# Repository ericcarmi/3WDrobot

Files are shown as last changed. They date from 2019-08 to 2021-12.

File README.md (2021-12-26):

# 3WD omnidirectional robot

This repo has code for Arduino (control) and ROS (network, GUI).
Also contains CAD files: camera mount, stepper motor/linear actuator to move a microphone up and down. 

The motiviation for this EEE Master's project was from a physics Senior project (an undergrad course) where I designed, 3D printed, and measured an acoustic lens in the anechoic chamber at CSUS. Measuring was tedious and not very precise, so making a robot to do the measuring seemed like a good next step. I only had one semester to do the EEE Master's project, so the solution is not "pretty". I brought the chassis for the robot but I did everything else myself: programming the controls (kinematics for 3-wheel drive), designing and 3D printer attachments (camera holders, linear actuator for mic movement), and programming the UI to control and monitor the robot (in ROS).  

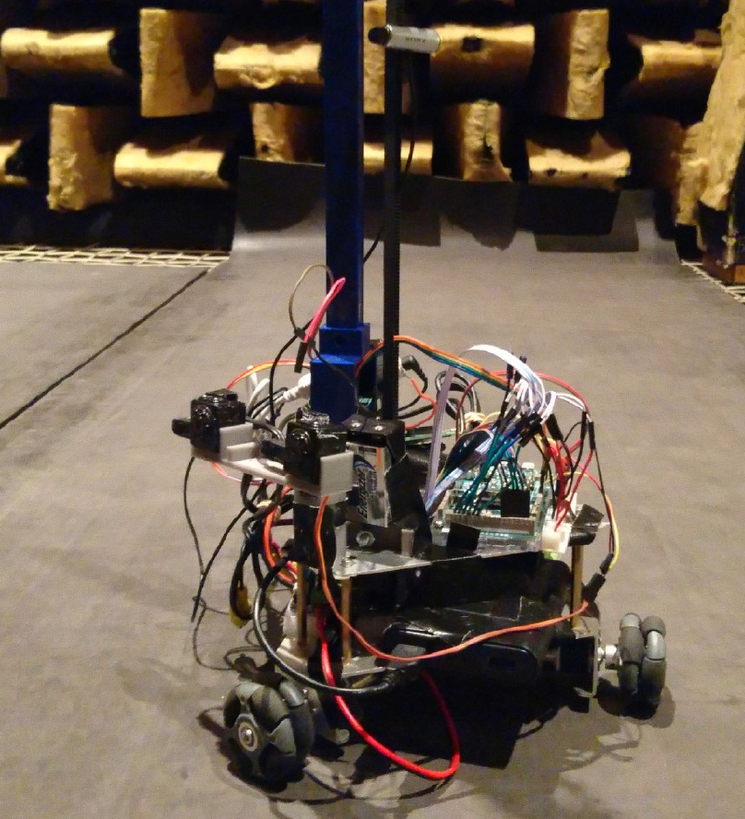
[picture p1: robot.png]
Robot in the anechoic chamber 3WD robot


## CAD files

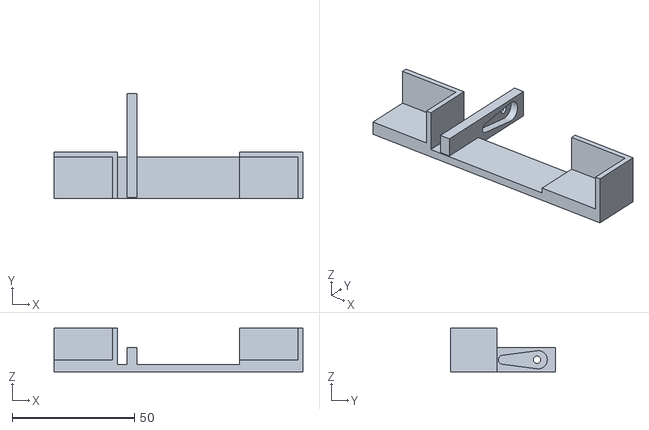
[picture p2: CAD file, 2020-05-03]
CAD files/cammountMain.stl
102.0 x 43.0 x 18.0

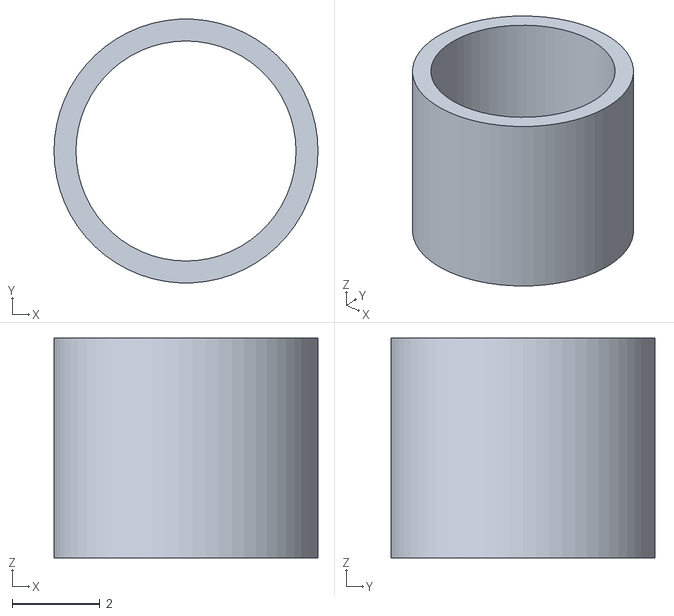
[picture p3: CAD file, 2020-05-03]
CAD files/lens/spacer.stl
6.00 x 5.99 x 5.00

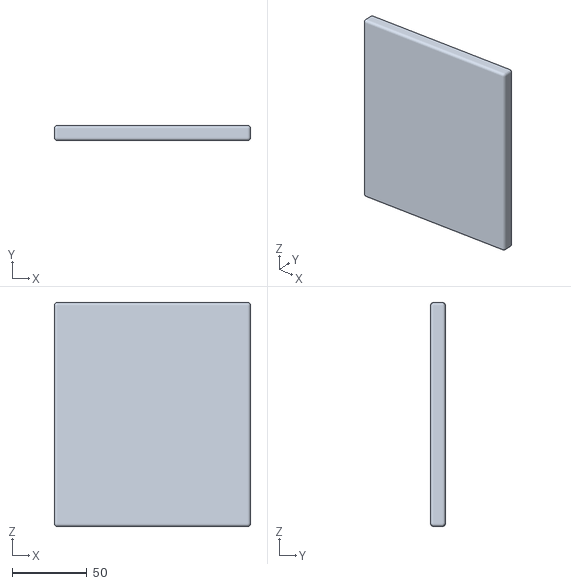
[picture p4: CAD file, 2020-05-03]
CAD files/speakerbase.stl
131.5 x 10.0 x 150.0

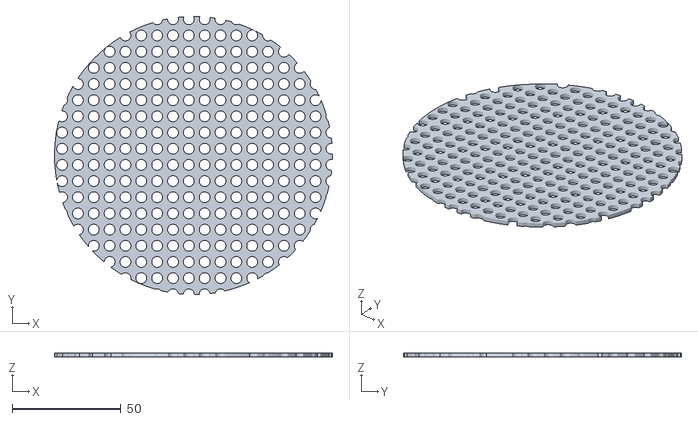
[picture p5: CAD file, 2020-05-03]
CAD files/lens/lens1.stl
128.0 x 128.0 x 2.00

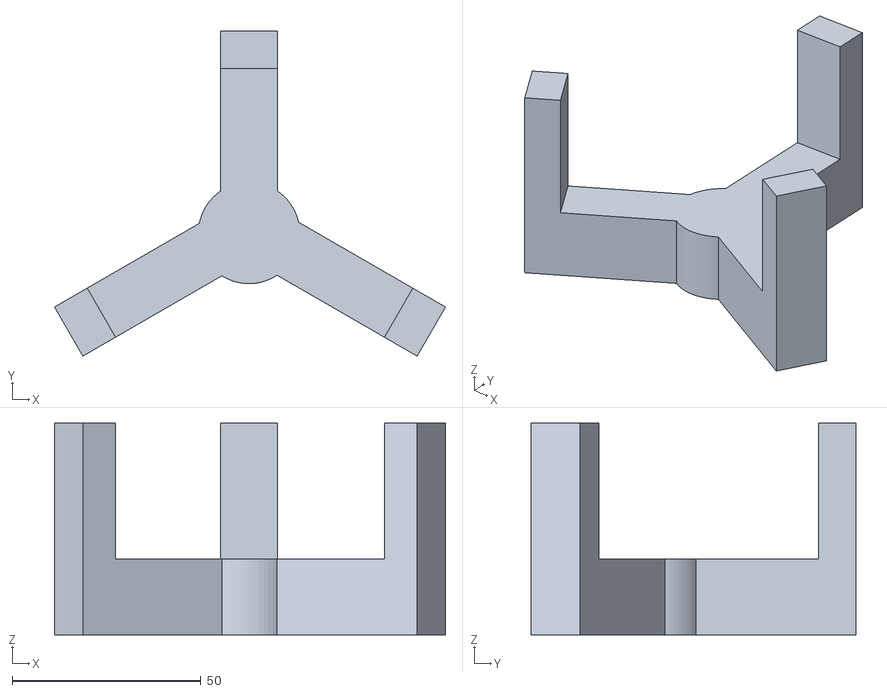
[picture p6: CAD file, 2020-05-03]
CAD files/omni3WDJack.stl
103.5 x 86.1 x 56.0

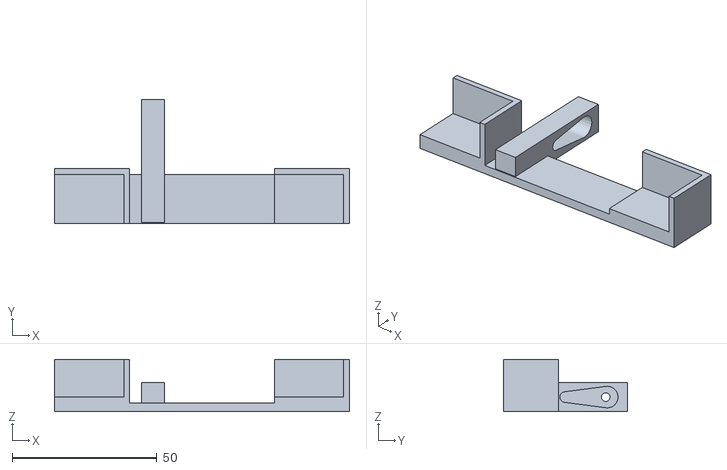
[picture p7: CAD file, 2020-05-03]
CAD files/cameraMount.stl
102.0 x 43.0 x 18.0

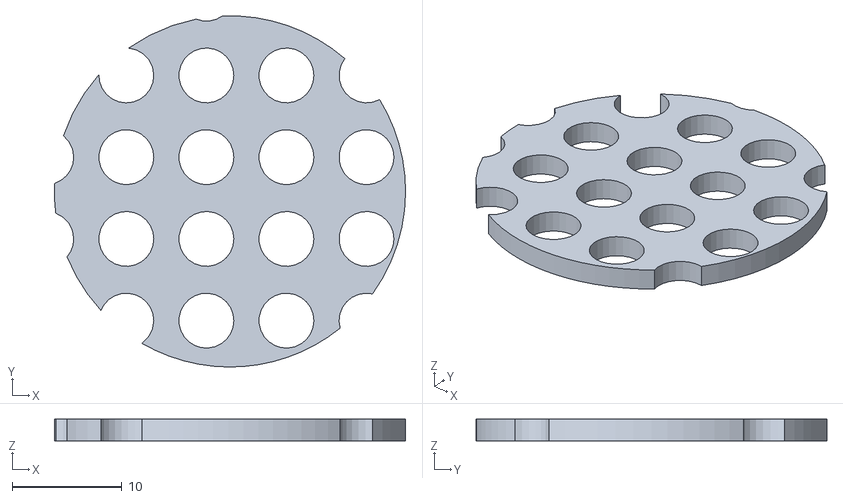
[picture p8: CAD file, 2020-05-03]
CAD files/lens/lens4.stl
32.0 x 32.0 x 2.00

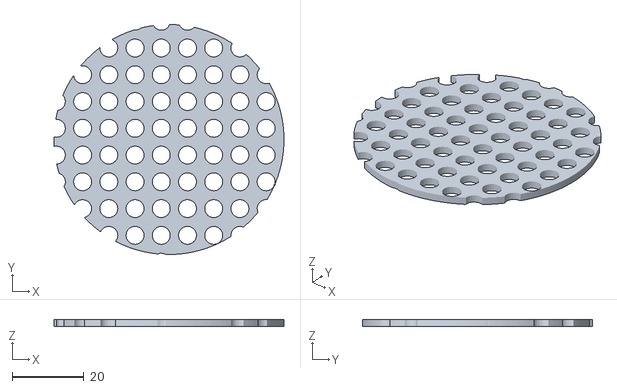
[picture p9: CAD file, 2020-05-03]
CAD files/lens/lens3.stl
64.0 x 64.0 x 2.00

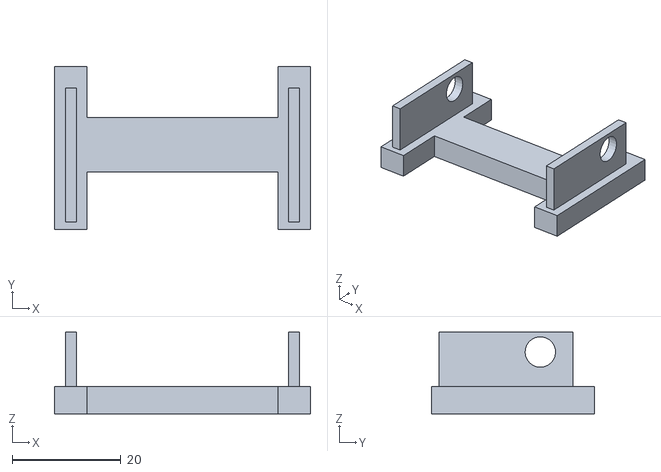
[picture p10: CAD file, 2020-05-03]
CAD files/stepperUnder.stl
47.0 x 30.0 x 15.0

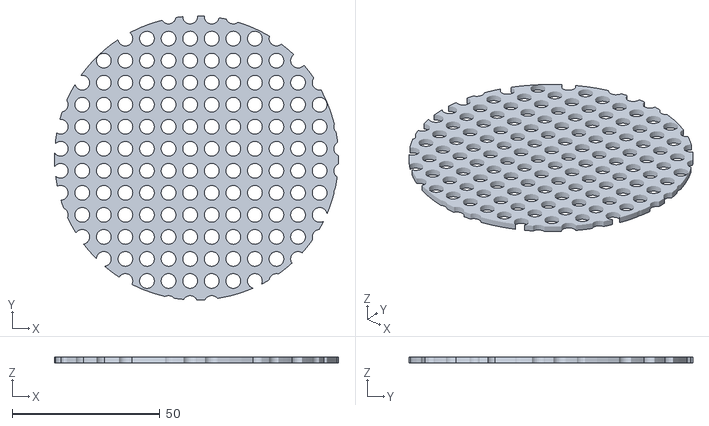
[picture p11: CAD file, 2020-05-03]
CAD files/lens/lens2.stl
96.0 x 96.0 x 2.00

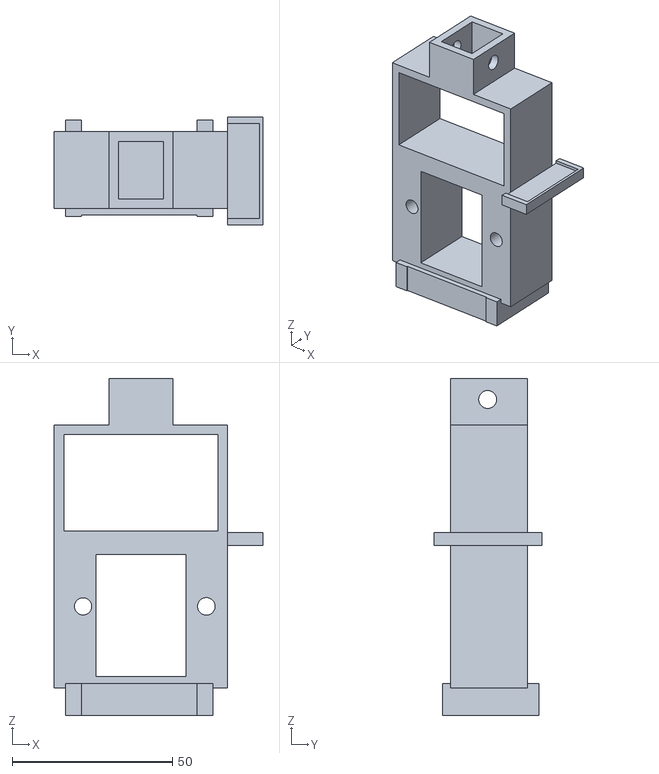
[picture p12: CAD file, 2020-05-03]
CAD files/stepperTop.stl
65.0 x 33.5 x 105.0

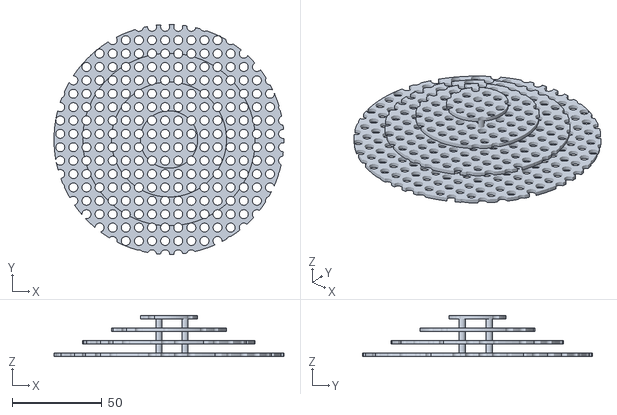
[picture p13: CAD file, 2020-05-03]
CAD files/lens/newlens.stl
128.0 x 128.0 x 23.0

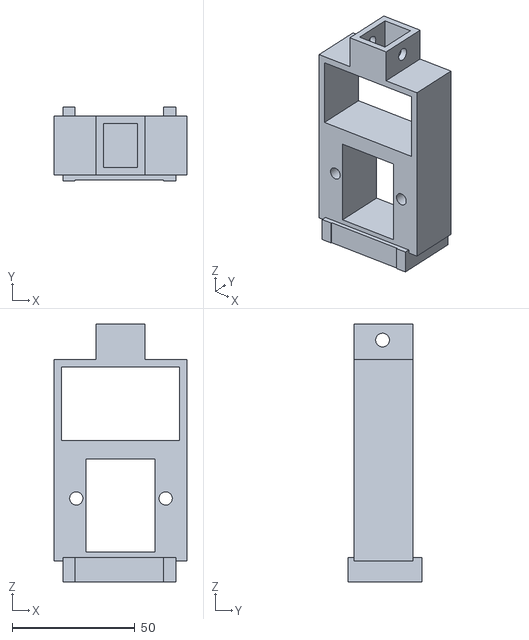
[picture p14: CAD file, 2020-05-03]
CAD files/smallstepperMount.stl
54.0 x 30.0 x 105.0

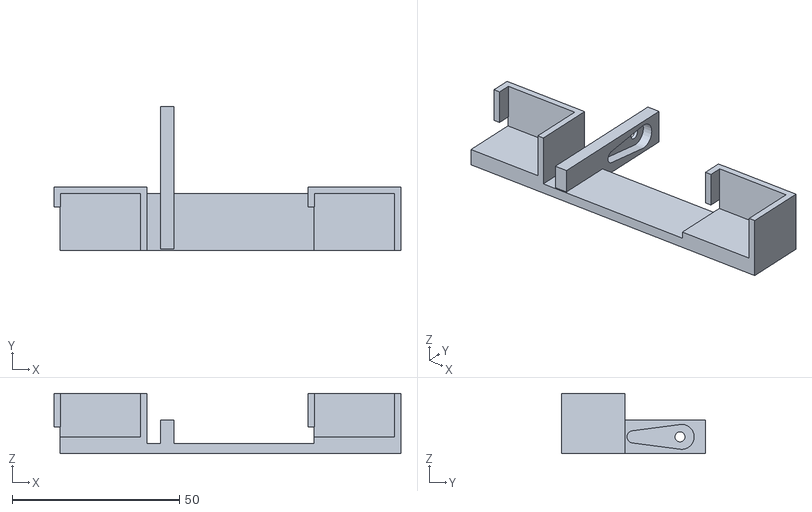
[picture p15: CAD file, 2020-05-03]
CAD files/cameraMount2.stl
103.9 x 43.0 x 18.0

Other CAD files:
CAD files/lens/lensconnect.stl
CAD files/hBridgeHolder.stl
CAD files/cammountUnderBase.stl
CAD files/cameraMount3.stl
CAD files/cammountBase.stl
CAD files/robotmount.stl
CAD files/speakercab.stl
CAD files/stepperBolt.stl
CAD files/stepperPulleyBolt.stl
CAD files/stpprMicTop.stl
CAD files/stpprtopbranch.stl

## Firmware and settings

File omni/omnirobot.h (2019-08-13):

#include "Motor.h"
#include "vision.h"
//#include "path.h"
# define sqrt3by2 0.8660254037844385965883021

struct Robot{
    Motor motor1, motor2, motor3;
    // Motor1 odometer increases moving to the right; 2 and 3 when moving forward

    Vision vision;

    float posx, posy, theta, vel_x, vel_y, vel_theta;
    float ang2 = -2*PI/3; // CW from motor 1 which is at front
    float ang3 = 2*PI/3;  // CCW
    float phi[3];
    float directionvector[2] = {0.0,1.0};
    float R = 0.116; // Branch length, from center to wheel
    float wheelradius = 0.024;  // 48mm diameter
    unsigned long currentTime, lastTime;
    float phiScaleFactor = 1.5;
    int localDRcount = 0;
    int drtemp1 = 0;
    int drtemp2 = 0;
    int minPWM = 1;
    float floatTime = 0.0f;
    float samplePeriod = 0.0f;
    float pathEndTime = 0.0f;
    float currentPathTime = 0.0f;
    bool DRflag;
    bool pathFlag = false;
    int pwmdelta1 = 0;
    int pwmdelta2 = 0;
    int pwmdelta3 = 0;

    // Directions for paths as described is orthogonal to wheel motion and direction pins
    int basicPaths[10][6] = {   {0,1,1,0,1,0},  // 0 Forward
                               {0,1,1,0,0,1},   // 1 Back
                               {2,1,1,1,0,0},   // 2 Left
                               {2,1,1,0,1,1},   // 3 Right
                               {1,0,1,1,0,0},   // 4 Forward left
                               {1,0,1,0,0,1},   // 5 Back right
                               {1,1,0,0,1,0},   // 6 Forward right
                               {1,1,0,1,0,0},   // 7 Back left
                               {1,1,1,0,0,0},
                               {1,1,1,1,1,1}};


    void outlineBasicPath(int x,int pwm)
    {
        motor1.setPWM(basicPaths[x][0]*pwm);
        motor2.setPWM(basicPaths[x][1]*pwm);
        motor3.setPWM(basicPaths[x][2]*pwm);
        motor1.setDirection(basicPaths[x][3]);
        motor2.setDirection(basicPaths[x][4]);
        motor3.setDirection(basicPaths[x][5]);

    }

    void outlineBasicPathTime(int x,int pwm, float t)
    {
        motor1.setPWM(basicPaths[x][0]*pwm);
        motor2.setPWM(basicPaths[x][1]*pwm);
        if(x == 2 or x == 3)
        {
          motor3.setPWM(basicPaths[x][2]*pwm-29);
        }
        else{motor3.setPWM(basicPaths[x][2]*pwm);}
        motor1.setDirection(basicPaths[x][3]);
        motor2.setDirection(basicPaths[x][4]);
        motor3.setDirection(basicPaths[x][5]);
        pathEndTime = t;
        currentPathTime = 0.0f;
        pathFlag = true;
    }

    void pathTransition(int x1, int x2, int pwm, float t)
    {
        pwmdelta1 = basicPaths[x2][0] - basicPaths[x1][0];
        pwmdelta2 = basicPaths[x2][1] - basicPaths[x1][1];
        pwmdelta3 = basicPaths[x2][2] - basicPaths[x1][2];

    }

    void checkPathTime()
    {
      if( (int)currentPathTime > (int)pathEndTime )
      {
        stopMoving();
        pathFlag = false;
        currentPathTime = 0.0f;
      }
    }

    void stopMoving()
    {
        motor1.setPWM(0);
        motor2.setPWM(0);
        motor3.setPWM(0);
    }

    // Get offset from encoders over one path time
    void calibrateWithPaths(int x, int pwm, float t)
    {
      int n1 = motor1.numrotations;
      int n2 = motor2.numrotations;
      int n3 = motor3.numrotations;
      outlineBasicPathTime(x, pwm, t);
      int n1b = motor1.numrotations;
      int n2b = motor2.numrotations;
      int n3b = motor3.numrotations;

      if(x == 0 or x == 1)
      {
        int delta = abs(n2b - n2) - abs(n3b - n3);

        if( delta > 0) // Motor 2 changed more
        {
            motor3.pwmOffset = delta*0.1;
        }
        else if(delta < 0)
        {
          motor2.pwmOffset = delta*0.1;
        }
      }


    }

    void moveByN(int N1, int N2, int N3)
    {
        motor1.moveByN(N1);
        motor2.moveByN(N2);
        motor3.moveByN(N3);
        DRflag = true;
    }

    void setPWM(int x1, int x2, int x3)
    {
      if( x1 > 0){motor1.setDirection(HIGH);}
      else{motor1.setDirection(LOW);}
      if( x2 > 0){motor2.setDirection(HIGH);}
      else{motor2.setDirection(LOW);}
      if( x3 > 0){motor3.setDirection(HIGH);}
      else{motor3.setDirection(LOW);}
      motor1.setPWM(abs(x1));
      motor2.setPWM(abs(x2));
      motor3.setPWM(abs(x3));
    }

    void updateDR()
    {
        motor1.updateDR(floatTime);
        motor2.updateDR(floatTime);
        motor3.updateDR(floatTime);

    }
    // Convert desired x,y and angular velocity into rotational velcoities
    // Theta should always be 0? Local orientation is fixed, changing theta offsets everything
    void vel2phi(float vx, float vy, float vtheta)
    {
        float temp1 = cos(theta);
        phi[0] = (vy + R*vtheta)/wheelradius;
        phi[1] = (sqrt3by2*vx - 0.5*vy + R*vtheta)/wheelradius;
        phi[2] = (-sqrt3by2*vx - 0.5*vy + R*vtheta)/wheelradius;

        if(phi[0] > 0){ motor1.setDirection(HIGH);}
        else{motor1.setDirection(LOW);}
        if(phi[1] > 0){ motor2.setDirection(HIGH);}
        else{motor2.setDirection(LOW);}
        if(phi[2] > 0){ motor3.setDirection(HIGH);}
        else{motor3.setDirection(LOW);}

        motor1.setPWM(abs(phi[0]));
        motor2.setPWM(abs(phi[1]));
        motor3.setPWM(abs(phi[2]));

    }


    void getPosition()
    {
        posx =  -2*sin(PI/3)*motor2.numrotations + 2*cos(PI/6)*motor3.numrotations;
        posy = 2*motor1.numrotations + cos(PI/3)*motor2.numrotations - 2*sin(PI/6)*motor3.numrotations;
        theta = R * (motor1.numrotations + motor2.numrotations + motor3.numrotations);

    }

    // This is a measurement that can be compared with the desired for PID control

    void setPosition(float targetx, float targety, float targettheta)
    {
        float temp1 = cos(theta);
        // Calculate number of rotations for each motor
        phi[0] = (targety + R*targettheta)/wheelradius;
        phi[1] = (sqrt3by2*targetx - 0.5*targety + R*targettheta)/wheelradius;
        phi[2] = (-sqrt3by2*targetx - 0.5*targety + R*targettheta)/wheelradius;

        motor1.moveByN(phi[0]);
        motor2.moveByN(phi[1]);
        motor3.moveByN(phi[2]);

        motor1.DRflag=true;
        motor2.DRflag=true;
        motor3.DRflag=true;
        DRflag=true;
    }
    // This is a calibration function for determining the min PWM value to achieve movement, varies with terrain
    // Test values and increase until movement is detected
    void getMinPWM()
    {
        motor1.temprotations = motor1.numrotations;
        for(int i = 0; i < 50; i++)
        {
            motor1.setPWM(i);
            delay(10);
            if((motor1.temprotations - motor1.numrotations) > 0)
            {
               minPWM = i;
               break;
            }
        }
    }

    void tracePaths()
    {
      int P = 4;
      int pwm = 40;
    if(floatTime < P)
  {
    outlineBasicPath(0,pwm);
  }
  if(floatTime < 2*P && floatTime > P)
  {
    outlineBasicPath(1,pwm);
  }
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

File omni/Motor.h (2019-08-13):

struct Motor{
  int encoderpins[2];
  int driverpins[3];
  int forward;
  int pwm;
  int encoderstates[4]; // A(k), A(k-1), B(k), B(k-1)
  int numrotations;
  int lastnumrotations;
  int inverserotations = 0;
  int temprotations;
  int diffnumrotations = 0;
  int encoderdirection;
  int encoderphase[2];
  int encoderphaseD;
  bool DRflag = false;
  float oneRotation = 567.0f; // Number of encoder clicks
  float wheelDistance = PI * 4.8/oneRotation;
  // 48 mm wheel diameter
  unsigned long currentTime;
  unsigned long lastTime;
  float velocity = 0.0f;
  float velocity_1 = 0.0f;
  float velocity_mem[5] = {0.0f,0.0f,0.0f,0.0f,0.0f};
  float vel_avg = 0.0f;
  float dv1 = 0.0f;
  float dt = 0.0f;
  int zerocounter = 0;

  int rotationError = 0;
  int targetNumRotations = 0;
  float rotationError_1 = 0.0f;
  float rotationErrorIntegral = 0.0f;
  float rotationErrorIntegral_1 = 0.0f;
  float PIout = 0.0f;

  float Kp_rotErr = 0.1f;
  float Ki_rotErr = 0.005f;

  int pwmOffset = 0;
  int pwmError = 0;
  int targetPWM = 0;
  float pwmError_1 = 0.0f;
  float pwmErrorIntegral = 0.0f;
  float pwmErrorIntegral_1 = 0.0f;
  float pwmPIout = 0.0f;

  float Kp_pwmErr = 0.5f;
  float Ki_pwmErr = 0.05f;

  void setencoderPins(int p1, int p2)
  {
    encoderpins[0] = p1;
    encoderpins[1] = p2;
    encoderstates[0] = LOW;
    encoderstates[1] = LOW;
    encoderstates[2] = LOW;
    encoderstates[3] = LOW;
    encoderphase[0] = 0;
    encoderphase[1] = 0;
    encoderphaseD = 0;
    numrotations = 0;
    lastnumrotations = 0;
    pinMode(encoderpins[0],INPUT);
    pinMode(encoderpins[1],INPUT);

  }

  void setdriverPins(int p1, int p2, int p3) // Forward, Backward, PWM/speed
  {
    driverpins[0] = p1;
    driverpins[1] = p2;
    driverpins[2] = p3;

    pinMode(driverpins[0],OUTPUT);
    pinMode(driverpins[1],OUTPUT);
    pinMode(driverpins[2],OUTPUT);

  }

  void setPWM(int x)
  {
    pwm = x + pwmOffset;
    analogWrite(driverpins[2],pwm);
  }

  void setDirection(int dir)
  {
    digitalWrite(driverpins[0],dir);
    digitalWrite(driverpins[1],!dir);
    forward=dir;
  }

  void updateencoderState()
  {
      if(encoderstates[0])
      {
          if(encoderstates[2])
          {
              encoderphase[0] = 3;
              encoderphaseD = encoderphase[0] - encoderphase[1];
              if(encoderphaseD == 2){numrotations--;}
              else if(encoderphaseD == 1){numrotations++;}
          }
          else
          {
              encoderphase[0] = 2;
              encoderphaseD = encoderphase[0] - encoderphase[1];
              if(encoderphaseD == -1){numrotations--;}
              else if(encoderphaseD == 2){numrotations++;}
          }
      }
      else
      {
          if(encoderstates[2])
          {
              encoderphase[0] = 1;
              encoderphaseD = encoderphase[0] - encoderphase[1];
              if(encoderphaseD == 1){numrotations--;}
              else if(encoderphaseD == -2){numrotations++;}
          }
          else
          {
              encoderphase[0] = 0;
              encoderphaseD = encoderphase[0] - encoderphase[1];
              if(encoderphaseD == -2){numrotations--;}
              else if(encoderphaseD == -1){numrotations++;}
          }
      }

      inverserotations = -1*numrotations;
      encoderphase[1] = encoderphase[0];
      currentTime = millis();
      dt = (float)(currentTime-lastTime)*0.001f;
      lastTime = currentTime;
      // Update velocity based on difference between numrotations and lastrotation


      diffnumrotations = numrotations - lastnumrotations;
      lastnumrotations = numrotations;

      velocity = diffnumrotations* 0.048f/dt/oneRotation;



  }

  void velmemdelay(float x)
  {
    velocity_mem[4] = velocity_mem[3];
    velocity_mem[3] = velocity_mem[2];
    velocity_mem[2] = velocity_mem[1];
    velocity_mem[1] = velocity_mem[0];
    velocity_mem[0] = x;
  }


  // Set desired number of rotations...convert this to mm eventually
  void moveByN(int target)
  {
      targetNumRotations = target;
      DRflag = true;
  }

  void setPWMTarget(int x)
  {
      targetPWM = x;
  }


  void pwmPID()
  {
        pwmError = targetPWM - pwm;
        // PI control
        pwmErrorIntegral = pwmErrorIntegral_1 +  (float)(pwmError);
        if(pwmErrorIntegral > 10)
        {
          pwmErrorIntegral = 0;
        }
        pwmPIout = (float)(Kp_pwmErr * pwmError + Ki_pwmErr * pwmErrorIntegral);
        if(pwmPIout > 0)
        {
          setDirection(HIGH);
        }
        else
        {
          setDirection(LOW);
        }
        setPWM(abs(pwmPIout));
        pwmError_1 = pwmError;
        pwmErrorIntegral_1 = pwmErrorIntegral;
  }

};
